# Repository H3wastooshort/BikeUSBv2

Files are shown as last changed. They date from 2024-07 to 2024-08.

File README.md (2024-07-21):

# BikeUSB v2 *(WIP)*
a rendered animation of the PCB roatating

Ever wanted to charge your phone of your bikes dynamo?
This Project does just that, for cheap (ish).

## Working Principle
The incoming AC voltage from the dynamo gets rectified by 4 shottky-diodes and buffered in a high-capacity capacitor.
Once a sufficient driving speed is reached and the capacitor is charged enough, the ATtiny1616 MCU on the board wakes up.

It measures the frequency of incoming AC voltage, which is corrolated to the driving speed, until it reaches the first threshold.
Once the first threshold is reached, it can be assumed that enough power is available to charge the phone at 2.5W.
The MCU enables the high efficiency DC/DC-Converter IC to generate 5V at the USB Type C Port.
The pull-ups in the FUSB302 IC are set to signal to the attached device that 2.5W (500mA) are available.
This prevents constant starting and stopping of the charging process, which is annoying.
If the frequency is high enough to reach the 5W or 7.5W thresholds, 5W or 7.5W will be signaled via USB C power delivery.

If the device detects a DC source, it enters configuration mode. In configuration mode, the 2 buttons are used to select which threshold to calibrate.
Connecting it back to a bike dynamo, it is now in calibration mode.
The MCU will detect the needed speed to generate enough power for the prev. selected power level by connecting a 3W, 6W, or 9W constant power load and driving at a steadily increasing speed.
Once the PowerGood signal does not drop out for 5 seconds with the load connected, a sufficient speed has been reached and is saved to EEPROM.

## Schematic
the schematic

## PCB
a rendered image of the PCB front
a rendered image of the PCB back

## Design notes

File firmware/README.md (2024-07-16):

# firmwares

## BikeUSBv2
the "main" firmware for the thing. this is probably what you want.

## BikeUSBv2_FUSB_test
manual communication wit the fusb for testing

## BikeUSBv2_test_generator
generates frequency on pin 7 and reads A0 to make up for me not having an oscilloscope or function generator

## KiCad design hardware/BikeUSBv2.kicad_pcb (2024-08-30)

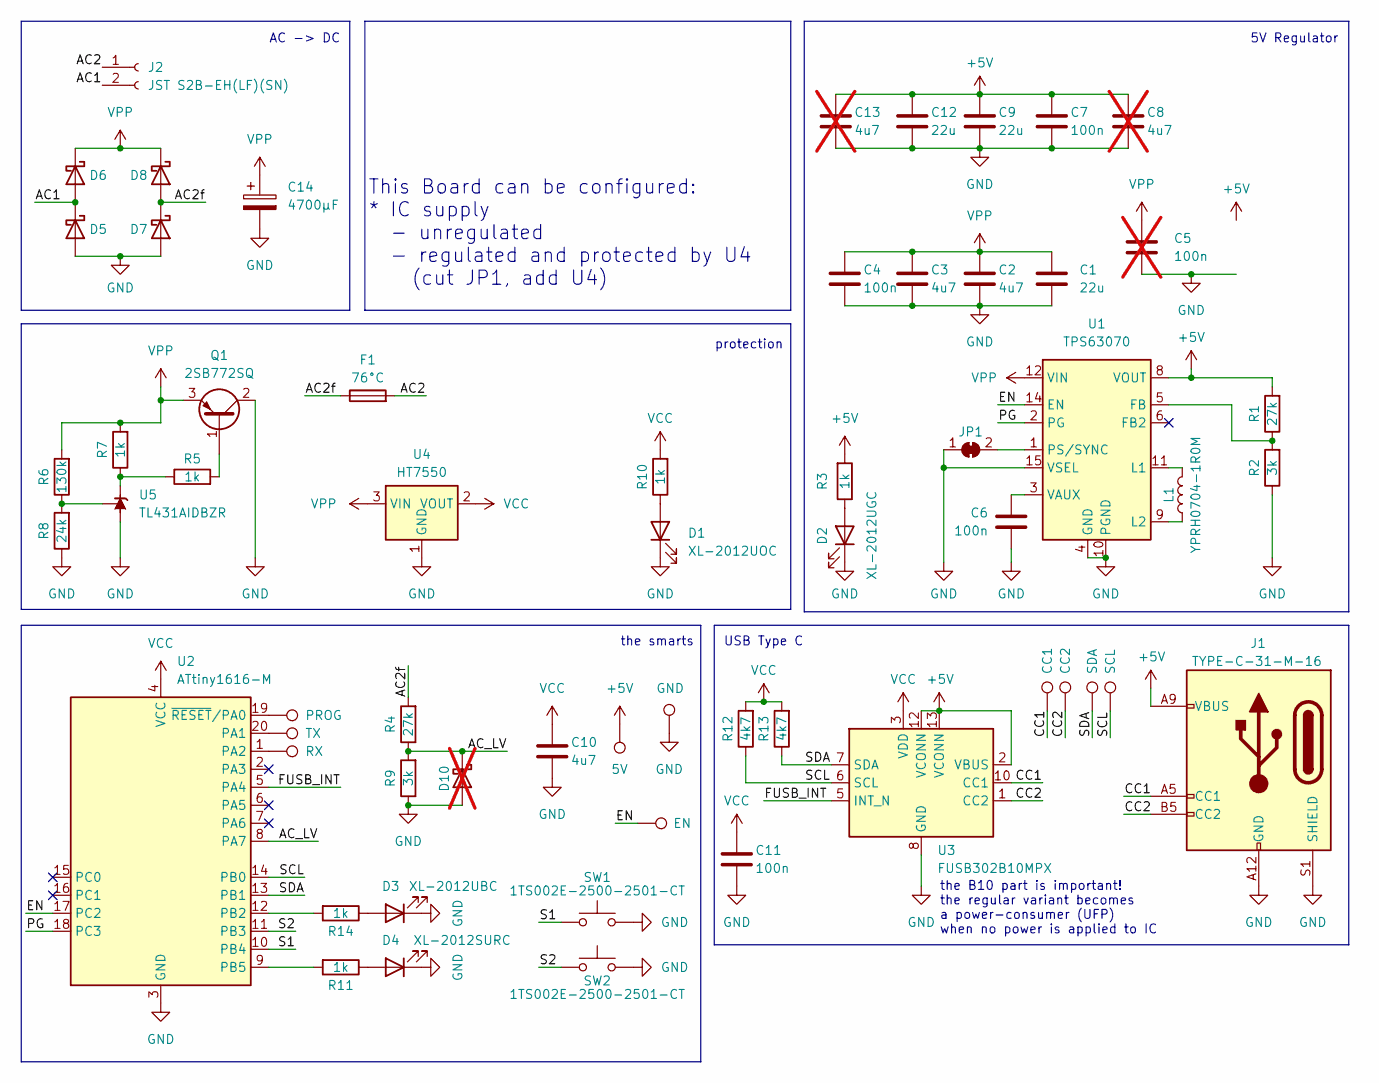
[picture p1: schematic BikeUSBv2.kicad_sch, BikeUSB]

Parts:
C1, C9, C12: 22u; C_1206_3216Metric_Pad1.33x1.80mm_HandSolder; LCSC C12891
C2, C3, C10: 4u7; C_0805_2012Metric_Pad1.18x1.45mm_HandSolder; LCSC C1779
C4, C6, C7, C11: 100n; C_0805_2012Metric_Pad1.18x1.45mm_HandSolder; LCSC C1711
C5: 100n; C_0603_1608Metric_Pad1.08x0.95mm_HandSolder; not fitted
C8, C13: 4u7; C_0805_2012Metric_Pad1.18x1.45mm_HandSolder; LCSC C1779; not fitted
C14: 4700µF; CP_Radial_D8.0mm_P5.00mm; LCSC C47893
D1: XL-2012UOC; LED_0805_2012Metric_Pad1.15x1.40mm_HandSolder; LCSC C965813
D2: XL-2012UGC; LED_0805_2012Metric_Pad1.15x1.40mm_HandSolder; LCSC C965815
D3: XL-2012UBC; LED_0805_2012Metric_Pad1.15x1.40mm_HandSolder; LCSC C965817
D4: XL-2012SURC; LED_0805_2012Metric_Pad1.15x1.40mm_HandSolder; LCSC C965812
D5, D6, D7, D8: CMS04(TE12L,Q,M); D_SOD-128; LCSC C603062
D10: D_PowerDI-123; not fitted
F1: 76°C; SETfuse X-Series; Part # X0; LCSC C22396315
J1: TYPE-C-31-M-16; TYPE-C-SMD_TYPE-C-31-M-16; LCSC C283541
J2: JST S2B-EH(LF)(SN); JST_EH_S2B-EH_1x02_P2.50mm_Horizontal; LCSC C514173
JP1: SolderJumper_2_Bridged; SolderJumper-2_P1.3mm_Bridged_RoundedPad1.0x1.5mm
L1: YPRH0704-1R0M; L_7.3x7.3_H4.5; LCSC Part C338840
Q1: 2SB772SQ; SOT-89-3_Handsoldering; LCSC C5158798
R1, R4: 27k; R_0805_2012Metric_Pad1.20x1.40mm_HandSolder; LCSC C375523
R2, R9: 3k; R_0805_2012Metric_Pad1.20x1.40mm_HandSolder; LCSC C218519
R3, R5, R7, R10, R11, R14: 1k; R_0805_2012Metric_Pad1.20x1.40mm_HandSolder; LCSC C110774
R6: 130k; R_0805_2012Metric_Pad1.20x1.40mm_HandSolder; LCSC C2831651
R8: 24k; R_0805_2012Metric_Pad1.20x1.40mm_HandSolder; LCSC C218452
R12, R13: 4k7; R_0805_2012Metric_Pad1.20x1.40mm_HandSolder; LCSC C17673
SW1, SW2: 1TS002E-2500-2501-CT; SW_SPST_CK_RS282G05A3; LCSC C255802
TP1: EN; TestPoint_Pad_D1.0mm
TP2: 5V; TestPoint_Pad_D2.5mm
TP3: GND; TestPoint_Pad_D2.5mm
TP4: PROG; TestPoint_Pad_D2.5mm
TP5: TX; TestPoint_Pad_D2.5mm
TP6: CC1; TestPoint_Pad_D1.5mm
TP7: CC2; TestPoint_Pad_D1.5mm
TP8: SDA; TestPoint_Pad_D1.5mm
TP9: SCL; TestPoint_Pad_D1.5mm
TP10: RX; TestPoint_Pad_D2.5mm
U1: TPS63070; VQFN-HR-15_L3.0-W2.5-P0.50-BL_TPS63070RNMR; LCSC C109322
U2: ATtiny1616-M; VQFN-20-1EP_3x3mm_P0.4mm_EP1.7x1.7mm; LCSC C507118
U3: FUSB302B10MPX; WQFN-14-1EP_2.5x2.5mm_P0.5mm_EP1.45x1.45mm; LCSC C891305
U4: HT7550; SOT-23_Handsoldering; LCSC C5279053
U5: TL431AIDBZR; SOT-23_Handsoldering; LCSC C23892

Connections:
+5V: C7.1, C8.1, C9.1, C12.1, C13.1, J1.A9 (VBUS), J1.B9 (VBUS), R1.2, R3.2, TP2.1, U1.7 (VOUT), U1.8 (VOUT), U3.2 (VBUS), U3.12 (VCONN), U3.13 (VCONN)
/ AC_LV: D10.1 (K), R4.1, R9.2, U2.8 (PA7)
/AC1: D5.1 (K), D6.2 (A), J2.2
/AC2: F1.2, J2.1
/AC2f: D7.1 (K), D8.2 (A), F1.1, R4.2
/CC1: J1.A5 (CC1), TP6.1, U3.10 (CC1), U3.11 (CC1)
/CC2: J1.B5 (CC2), TP7.1, U3.1 (CC2), U3.14 (CC2)
/EN: TP1.1, U1.14 (EN), U2.17 (PC2)
/FUSB_INT: U2.5 (PA4), U3.5 (INT_N)
/PG: U1.2 (PG), U2.18 (PC3)
/S1: SW1.1, U2.10 (PB4)
/S2: SW2.1, U2.11 (PB3)
/SCL: R12.1, TP9.1, U2.14 (PB0), U3.6 (SCL)
/SDA: R13.1, TP8.1, U2.13 (PB1), U3.7 (SDA)
GND: C1.2, C2.2, C3.2, C4.2, C5.2, C6.2, C7.2, C8.2, C9.2, C10.2, C11.2, C12.2, C13.2, C14.2, D1.1 (K), D2.1 (K), D3.1 (K), D4.1 (K), D5.2 (A), D7.2 (A), D10.2 (A), J1.A12 (GND), J1.B12 (GND), J1.S1 (SHIELD), JP1.1 (A), Q1.2 (C), R2.1, R8.1, R9.1, SW1.2, SW2.2, TP3.1, U1.4 (GND), U1.10 (PGND), U1.15 (VSEL), U2.3 (GND), U2.21 (GND), U3.8 (GND), U3.9 (GND), U3.15 (GND), U4.1 (GND), U5.3 (A)
unnamed: D1.2 (A), R10.1
unnamed: D2.2 (A), R3.1
unnamed: D3.2 (A), R14.1
unnamed: D4.2 (A), R11.1
unnamed: JP1.2 (B), U1.1 (PS/SYNC)
unnamed: Q1.1 (B), R5.2
unnamed: R1.1, R2.2, U1.5 (FB)
unnamed: L1.1, U1.11 (L1)
unnamed: L1.2, U1.9 (L2)
unnamed: C6.1, U1.3 (VAUX)
unnamed: TP5.1, U2.20 (PA1)
unnamed: TP10.1, U2.1 (PA2)
unnamed: R14.2, U2.12 (PB2)
unnamed: R11.2, U2.9 (PB5)
unnamed: TP4.1, U2.19 (~RESET/PA0)
unnamed: R5.1, R7.1, U5.1 (K)
unnamed: R6.1, R8.2, U5.2 (REF)
VCC: C10.1, C11.1, R10.2, R12.2, R13.2, U2.4 (VCC), U3.3 (VDD), U3.4 (VDD), U4.2 (VOUT)
VPP: C1.1, C2.1, C3.1, C4.1, C5.1, C14.1, D6.1 (K), D8.1 (K), Q1.3 (E), R6.2, R7.2, U1.12 (VIN), U1.13 (VIN), U4.3 (VIN)

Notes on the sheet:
the smarts
AC -> DC
the B10 part is important! the regular variant becomes a power-consumer (UFP) when no power is applied to IC
USB Type C
5V Regulator
protection
This Board can be configured: * IC supply - unregulated - regulated and protected by U4 (cut JP1, add U4)

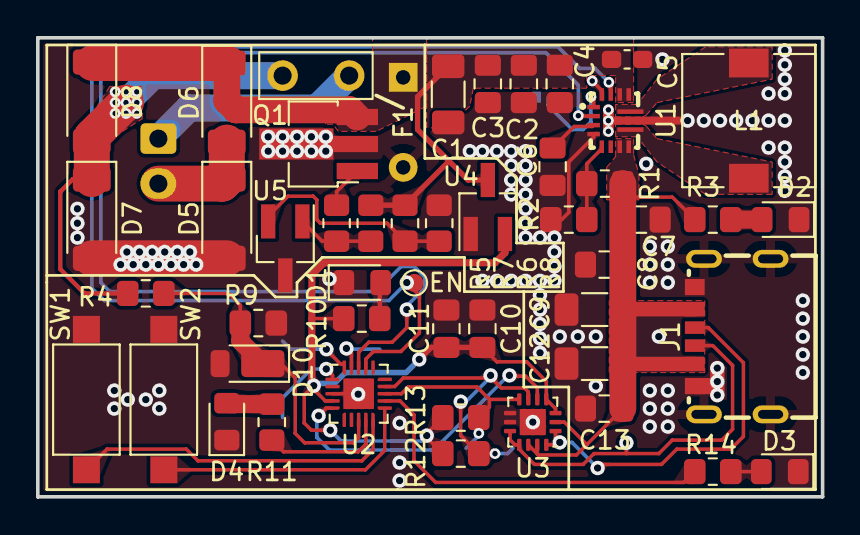
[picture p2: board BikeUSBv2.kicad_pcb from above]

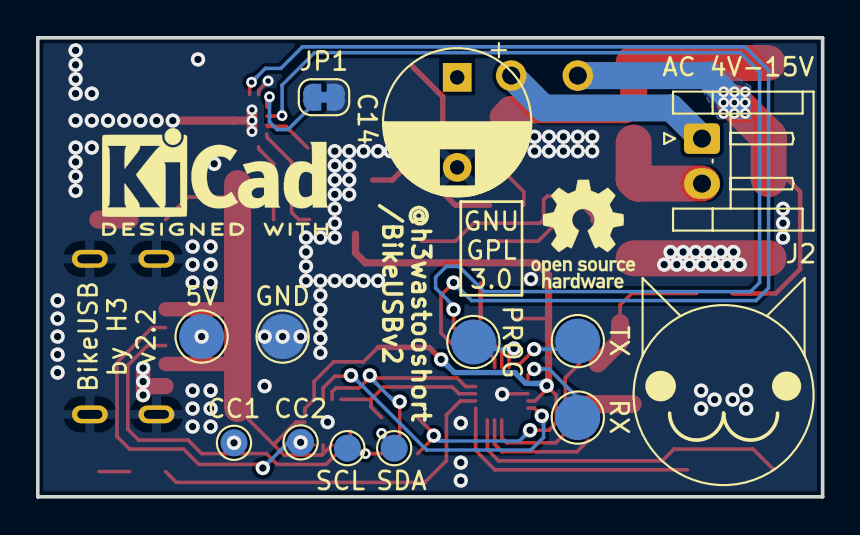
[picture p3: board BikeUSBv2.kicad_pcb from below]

Board: 2 copper layers, 43.6 x 25.5 mm, 61 parts (13 on the bottom side), 34 nets.

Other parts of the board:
CAT**: PCBcat

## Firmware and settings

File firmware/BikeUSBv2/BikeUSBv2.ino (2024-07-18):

/*
megaTinyCore Board Config:
BOD Mode = Active / Sampled (125Hz)
BOD Voltage Level = 2.6V
Chip = ATtiny 1616
Clock = 4Mhz Internal 
millis()/micros() = Enabled (default timer) or maybe RTC (no micros). not sure yet
printf() = Minimal
Startup Time = 64ms
Programmer: SerialUPDI - SLOW
*/

#include "includes.h"
#include "hardware.h"
#define FUSB_DEBUG_SERIAL Serial
#include "lib/PD_Friend/i2c/swi2c.h"
#include "lib/PD_Friend/pd_friend.h"
#include "debug.h"
#include "power.h"
#include "eeprom_util.h"
#include "config.h"
#include "main_state_machine.h"
#include "led.h"
#include "ac.h"
#include "power_levels.h"

BlinkyLED usr_led(USR_LED_PIN);
BlinkyLED pwr_led(PWR_LED_PIN);
SWI2C fusb_i2c(SDA_PIN, SCL_PIN, FUSB302_I2C_SLAVE_ADDR);
PDFriendI2C fusb_i2c_compat(fusb_i2c);
FUSB302 fusb(fusb_i2c_compat);
PDStack_SRC pd(fusb);

#include "pd_src.2.h"
#include "debug.2.h"
#include "config_mode.h"
#include "calibrate_mode.h"
#include "main_state_machine.2.h"
#include "buttons.h"

void setup() {
  _PROTECTED_WRITE(WDT.CTRLA, WDT_PERIOD_4KCLK_gc);
  wdt_reset();

  setupHardware();
  usr_led.setup();
  usr_led.setStatic(true);
  pwr_led.setup();

  Serial.pins(PIN_PA1, PIN_PA2);
  Serial.begin(38400);

  Serial.println();
  Serial.println();

  printDebug(DBG_RESET, GPIOR0);

  Serial.println();
  const char* boot_msg = "BikeUSBv2, compiled on ";
  const char* boot_msg_2 = " at ";
  Serial.print(boot_msg);
  Serial.print(__DATE__);
  Serial.print(boot_msg_2);
  Serial.print(__TIME__);
  Serial.println();
  printDebug(DBG_BOOT, 0x00);

  //load conf
  if (!loadConfig()) storeConfig();
  dumpConfig();
  printDebug(DBG_BOOT, 0x01);

  //I2C
  fusb_i2c.setStretchTimeout(10);
  fusb_i2c.begin();
  printDebug(DBG_BOOT, 0x02);

  //PD
  pd.init_src();
  printDebug(DBG_BOOT, 0x03);

  initAC();
  printDebug(DBG_BOOT, 0x04);

  //buttons
  button_setup();

  usr_led.setStatic(false);
  wdt_reset();

  printDebug(DBG_BOOT, 0x05);

  wdt_reset();
}

void loop() {
  //printDebug(DBG_LOOP, 0x00);
  AC_loop_counter();

  run_msm();
  run_pd();

  usr_led.loop();
  pwr_led.loop();

  handleSerialCommands();
  doDebugOutput();
  AC_new_meas_flag = false;  //anything using this should have run by now

  wdt_reset();
}

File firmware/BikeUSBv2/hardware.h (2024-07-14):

//====PINS====

const uint8_t OUTPUT_ENABLE_PIN = PIN_PC2;
const uint8_t OUTPUT_GOOD_PIN = PIN_PC3;

const uint8_t AC_MEASURE_PIN = PIN_PA7;  //also AINP0, don't change this or AC code must be changed aswell

const uint8_t SDA_PIN = PIN_PC0;
const uint8_t SCL_PIN = PIN_PC1;

const uint8_t FUSB_INT_PIN = PIN_PA4;

#define HAS_FUSB

const uint8_t BTN1_PIN = PIN_PB3;
const uint8_t BTN2_PIN = PIN_PB4;

const uint8_t USR_LED_PIN = PIN_PB5;
const uint8_t PWR_LED_PIN = PIN_PB2;

const uint8_t CC1_PIN = PIN_PB0;
const uint8_t CC2_PIN = PIN_PB1;
const uint8_t CC_DAC_PIN = PIN_PA6;

//====OTHER====

const uint16_t MIN_INPUT_VOLTAGE = 3000;  //in mV, minimum MCU supply voltage needed to allow operation of device
const float FREQ_HYST = 0.1; //10%

//============

void setupHardware() {
  //pin modes
  pinMode(OUTPUT_ENABLE_PIN, OUTPUT);
  digitalWrite(OUTPUT_ENABLE_PIN, LOW);
  pinMode(USR_LED_PIN, OUTPUT);

  //pinMode(AC_MEASURE_PIN, INPUT);
  pinMode(OUTPUT_GOOD_PIN, INPUT_PULLUP);
  pinMode(BTN1_PIN, INPUT_PULLUP);
  pinMode(BTN2_PIN, INPUT_PULLUP);

  pinMode(FUSB_INT_PIN, INPUT_PULLUP);

  //ADC0
  analogReadResolution(10);
  analogReference(INTERNAL2V5);  //set ADC reference to 2.5V as it covers the full range of CC voltages
}

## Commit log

2024-01-29 rough schematic
    [BikeUSBv2.kicad_pcb, BikeUSBv2.kicad_sch]
2024-01-29 some things
    [BikeUSBv2.kicad_sch]
2024-01-30 fine, im using an MCU
    [BikeUSBv2.kicad_sch]
2024-01-30 group things on PCB
    [BikeUSBv2.kicad_pcb, BikeUSBv2.kicad_sch]
2024-02-02 dont exactly remember what i did here, its from tuesday i think
    [BikeUSBv2.kicad_sch]
2024-02-02 placed components, started routing
    [BikeUSBv2.kicad_pcb, BikeUSBv2.kicad_sch]
2024-02-02 routing finished so far
    [BikeUSBv2.kicad_pcb, BikeUSBv2.kicad_sch]
2024-02-03 fix clearances, routing almost done
    [BikeUSBv2.kicad_pcb, BikeUSBv2.kicad_sch]
2024-02-03 idk, forgot to save that
    [BikeUSBv2.kicad_pcb]
2024-02-03 actually complete routing
    [BikeUSBv2.kicad_pcb]
2024-02-03 added pcb art, other stuff
    [BikeUSBv2.kicad_pcb, BikeUSBv2.kicad_sch]
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2024-02-03 better U1 cap layout
    [BikeUSBv2.kicad_pcb, BikeUSBv2.kicad_sch]
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2024-02-05 added footprint for clamping diode if needed
    [BikeUSBv2.kicad_pcb, BikeUSBv2.kicad_sch]
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2024-02-05 better inductor track layout
    [BikeUSBv2.kicad_pcb]
2024-02-05 forgot to rotate the protection silkscreen layer
    [BikeUSBv2.kicad_pcb]
2024-02-05 oops, those were actually the correct footprints...
    [BikeUSBv2.kicad_pcb]
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2024-02-05 more stuff i forgot
    [BikeUSBv2.kicad_pcb]
2024-02-05 teardrops + zone fills + other
    [BikeUSBv2.kicad_pcb]
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2024-02-07 forgot to save PCB
    [BikeUSBv2.kicad_pcb]
2024-02-08 smaller fixes
    [BikeUSBv2.kicad_pcb]
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2024-02-19 half capacitance, but cheaper
    [BikeUSBv2.kicad_pcb, BikeUSBv2.kicad_sch]
2024-02-21 switch CC current source strategy
    these newer attinys have a DAC!
    just use that for the current source!
    [BikeUSBv2.kicad_pcb, BikeUSBv2.kicad_sch]
2024-02-21 push components around, fix lcsc, add cap header
    [BikeUSBv2.kicad_pcb, BikeUSBv2.kicad_sch]
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2024-02-22 stop DRC from complaining
    [BikeUSBv2.kicad_pcb]
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2024-02-27 re-layout parts. routing TBD
    [BikeUSBv2.kicad_pcb]
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2024-03-16 fix DRC errors
    [BikeUSBv2.kicad_pcb]
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2024-05-05 fix schematic upload
2024-05-22 dumb mistake fixed
    i thought the feedback voltage had to be 2.5V at operating voltage. its actually 0.5V
    [BikeUSBv2.kicad_pcb, BikeUSBv2.kicad_sch]
2024-05-22 add proper PD negotiation
    [BikeUSBv2.kicad_pcb, BikeUSBv2.kicad_sch]
2024-05-23 add footprint for ldo-bodge
    [BikeUSBv2.kicad_pcb, BikeUSBv2.kicad_sch]
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2024-05-23 switch to FUSB302 without dead-battery charging
    [BikeUSBv2.kicad_sch]
2024-05-23 fixup lcsc
    [BikeUSBv2.kicad_pcb, BikeUSBv2.kicad_sch]
2024-05-23 silkscreen fixes
    [BikeUSBv2.kicad_pcb]
2024-05-23 change OVP protection scheme
    [BikeUSBv2.kicad_sch]
2024-05-23 apply changes to PCB
    [BikeUSBv2.kicad_pcb, BikeUSBv2.kicad_sch]
2024-05-23 add info note to sch
    [BikeUSBv2.kicad_sch]
2024-05-23 added resistor required in DS
    [BikeUSBv2.kicad_pcb, BikeUSBv2.kicad_sch]
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2024-05-23 remove leftover silkscreen text
    [BikeUSBv2.kicad_pcb]
2024-05-25 make schematic look nicer
    [BikeUSBv2.kicad_sch]
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2024-06-12 switch eFuse IC in design
    [BikeUSBv2.kicad_pcb, BikeUSBv2.kicad_sch]
2024-06-13 make U4 optional since new U5 clamps to 5V5
    [BikeUSBv2.kicad_pcb, BikeUSBv2.kicad_sch]
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2024-06-13 add therm relief for PTH
    [BikeUSBv2.kicad_pcb]
2024-06-13 fix stuff like thermals for U5
    [BikeUSBv2.kicad_pcb]
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2024-06-14 add INT line between U3 and U2
    [BikeUSBv2.kicad_pcb, BikeUSBv2.kicad_sch]
2024-06-14 space EN/PG tracks more + readd teardrops
    [BikeUSBv2.kicad_pcb]
2024-06-14 switch to SOT-23 voltage regulator
    [BikeUSBv2.kicad_pcb, BikeUSBv2.kicad_sch]
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2024-06-23 fix led.h
2024-06-29 pulled out too much
    [BikeUSBv2.ino]
2024-06-29 cut resistor-based negotiations
    7.5W is pretty unrealistic
    also, I2C needs pullups
    [BikeUSBv2.kicad_pcb, BikeUSBv2.kicad_sch]
2024-06-30 [PCB] change I2C to HW pins
    [BikeUSBv2.kicad_pcb, BikeUSBv2.kicad_sch]
2024-06-30 [PCB] fix Teardrops
    [BikeUSBv2.kicad_pcb]
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2024-07-01 [PCB] minor layout change
    [BikeUSBv2.kicad_pcb]
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2024-07-01 [PCB] switch schematic to different VREG
    [BikeUSBv2.kicad_sch]
2024-07-01 [PCB] rough layout with new BuckBoost IC
    [BikeUSBv2.kicad_pcb, BikeUSBv2.kicad_sch]
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2024-07-01 [PCB] fix DRC
    [BikeUSBv2.kicad_pcb]
2024-07-01 [PCB]
    OVP by zener and fuse for now...
    [BikeUSBv2.kicad_pcb, BikeUSBv2.kicad_sch]
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2024-07-01 [PCB] switch to different protection circuit
    [BikeUSBv2.kicad_pcb, BikeUSBv2.kicad_sch]
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2024-07-01 [PCB] fill in LCSC IDs
    [BikeUSBv2.kicad_pcb, BikeUSBv2.kicad_sch]
2024-07-01 shitty LTSpice sim of voltage limiter
    im assuming the generator won't put out more than 1A
2024-07-01 [PCB] layout less ugly
    [BikeUSBv2.kicad_pcb]
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2024-07-01 [PCB] via changes
    this might help with head conduction from the inductor
    [BikeUSBv2.kicad_pcb]
2024-07-01 [PCB] changed VREG RDIV for more accurate 5V
    prev 5.13V now 4.98V
    [BikeUSBv2.kicad_pcb, BikeUSBv2.kicad_sch]
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2024-07-02 [PCB] slight sch change
    [BikeUSBv2.kicad_pcb, BikeUSBv2.kicad_sch]
2024-07-02 [PCB] fix DRC, add TD
    [BikeUSBv2.kicad_pcb]
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2024-07-02 [PCB] thermal fuse footprint now right pitch
    [BikeUSBv2.kicad_pcb, BikeUSBv2.kicad_sch]
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2024-07-03 [PCB] add solder-covered heatsink surfaces
    [BikeUSBv2.kicad_pcb]
2024-07-03 [PCB] adjust rendered finish
    [BikeUSBv2.kicad_pcb]
2024-07-03 [PCB] silkscreen fixes
    [BikeUSBv2.kicad_pcb, BikeUSBv2.kicad_sch]
2024-07-03 [PCB] add voltage rating and OSHW symbol
    [BikeUSBv2.kicad_pcb]
2024-07-03 [PCB] silk and 3d
    [BikeUSBv2.kicad_pcb]
2024-07-11 decode error warning
    ahahahahaaaaahahahaaaa there is a 68 Ohm short between UPDI and TX, fucking hell, this is why i could not program it anymore, no clue where tf that short is though, can't see it by eye...
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2024-07-11 fix AC RDIV
    [BikeUSBv2.kicad_pcb, BikeUSBv2.kicad_sch]
2024-07-11 [PCB] fix resistors
    [BikeUSBv2.kicad_pcb, BikeUSBv2.kicad_sch]
2024-07-12 better butten handler, fix wdt resets
    [BikeUSBv2.ino, led.h]
2024-07-13 freq measurement
    there is a memory leak somewhere :/
    DBG_FREQ gets printed before DBG_AC, this means AC_new_meas_flag was set high by ????????
    [BikeUSBv2.ino, ac.h]
2024-07-14 trying to fix memory corruption???
    [BikeUSBv2.ino, ac.h]
2024-07-14 freq hyst, fix powerup
    [hardware.h]
2024-07-14 fix p level switching
2024-07-14 Revert "calc freq usinsing micros()"
    This reverts commit c99cfcac4402f8ccdf8a25f426e3dab792760c7d.
    [BikeUSBv2.ino, ac.h]
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2024-07-16 [PCB] move L1 back to leave more room for U1 heatsink
    [BikeUSBv2.kicad_pcb]
2024-07-16 [PCB] add kicad logo and gpl text
    [BikeUSBv2.kicad_pcb]
2024-07-17 debug failing i2c
2024-07-18 [PCB] move OSHW logo away from via
    [BikeUSBv2.kicad_pcb]
2024-07-18 [PCB] add CC testpads
    [BikeUSBv2.kicad_pcb, BikeUSBv2.kicad_sch]
2024-07-18 [PCB] move text and such
    [BikeUSBv2.kicad_pcb]
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2024-07-21 [PCB] add I2C testpads and improve groundplane
    [BikeUSBv2.kicad_pcb, BikeUSBv2.kicad_sch]
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2024-07-22 [PCB] add pullup-resistor for TL431
    [BikeUSBv2.kicad_pcb, BikeUSBv2.kicad_sch]
2024-07-22 [PCB] minor fixes
    [BikeUSBv2.kicad_pcb, BikeUSBv2.kicad_sch]
2024-07-22 [PCB] silkscreen fixes and geographical reannotate
    [BikeUSBv2.kicad_pcb, BikeUSBv2.kicad_sch]
2024-07-22 [PCB] add grounding tab
    [BikeUSBv2.kicad_pcb]
2024-08-30 [PCB] also protect diodes
    [BikeUSBv2.kicad_pcb, BikeUSBv2.kicad_sch]
2024-08-30 i did this ages ago
    sig gen now outputs correct hi-frq signal
    [BikeUSBv2_test_generator.ino]
